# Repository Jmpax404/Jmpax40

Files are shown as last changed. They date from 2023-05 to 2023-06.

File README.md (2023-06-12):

# Jmpax40 v1.0

Jmpax40 is a 40% wireless split keyboard.

## Tips

- 键位设置(/firmware/jmpax/jmpax.keymap)由在线配置工具完成，可以参考[https://github.com/Jmpax404/zmk-config](https://github.com/Jmpax404/zmk-config)

## Troubles

- 钢板卫星轴下面的PCB贴了元器件，导致无法平放卫星轴
- 定位板厚度打的3mm，导致无法卡入卫星轴，应该改用1.5mm的方案
- PCB上的3535正贴灯的标识是按照标准定义设置的，但是力创商城上[XL-3535RGBC-WS2812B](https://item.szlcsc.com/3033137.html)的引脚与其不一致
- 想做Nums、Caps等指示灯，但是ZMK官方仓库目前可能还没有这个功能

## References

感谢大佬们的开源和分享！

学习完下面的参考资料，您也能制作出属于自己的机械键盘。

[C_Go777 - [新手向]自制化键盘教程](https://space.bilibili.com/341864346/channel/collectiondetail?sid=196200)

[苏达酱 - 学完你就该去开团啦！](https://space.bilibili.com/7555349/channel/collectiondetail?sid=153786)

[人菜瘾大周传雄 - 从零制作蓝牙双模键盘DIY](https://space.bilibili.com/95393302/channel/collectiondetail?sid=8167)

[Joric - Jorne Wiki](https://github.com/joric/jorne/wiki)

[Joric - nRFMicro Wiki](https://github.com/joric/nrfmicro/wiki)

[ZMK官方文档](https://zmk.dev/docs)

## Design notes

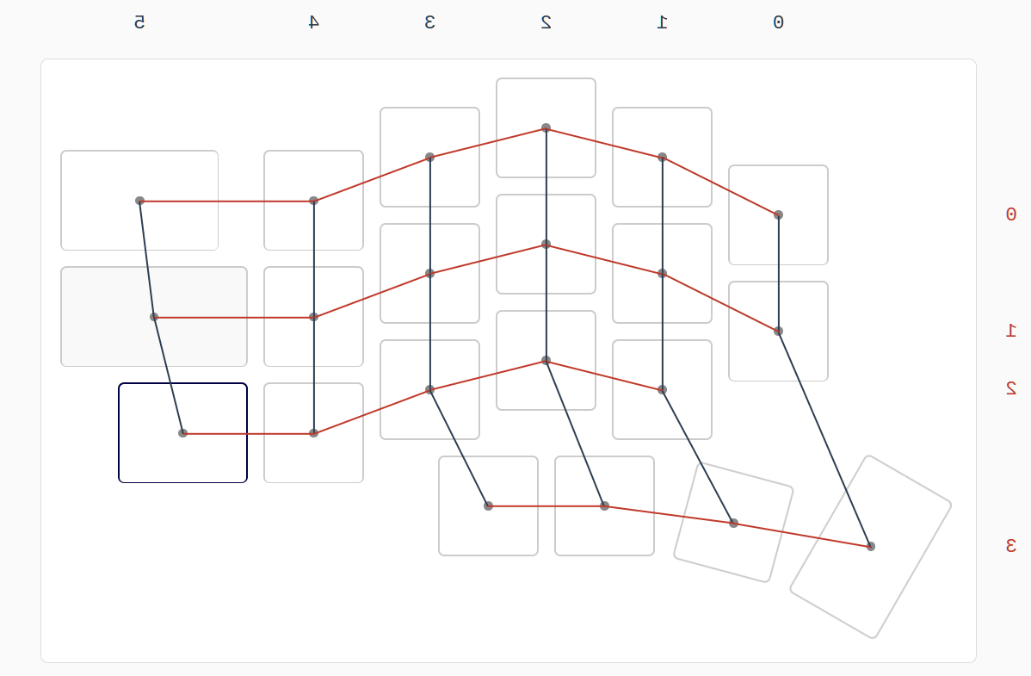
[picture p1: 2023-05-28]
pcb/matrix-right.png

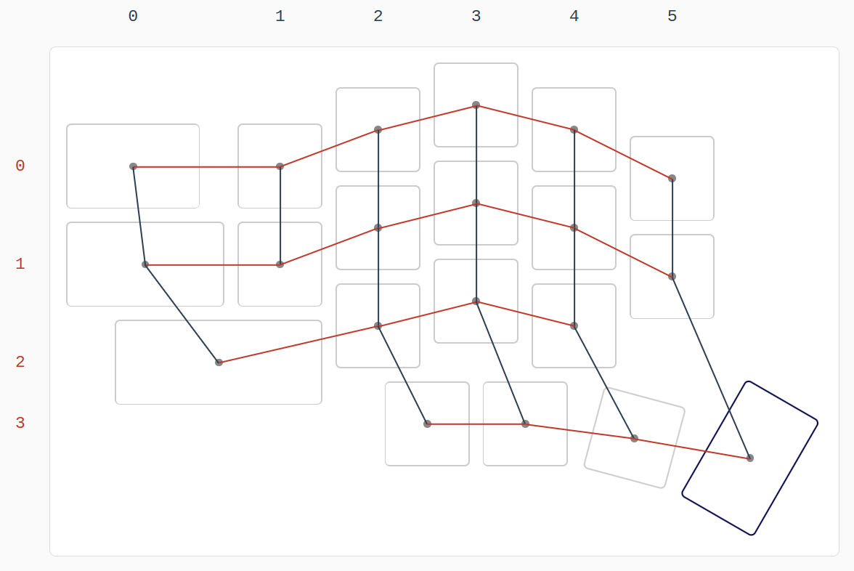
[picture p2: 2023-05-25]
pcb/matrix-left.png

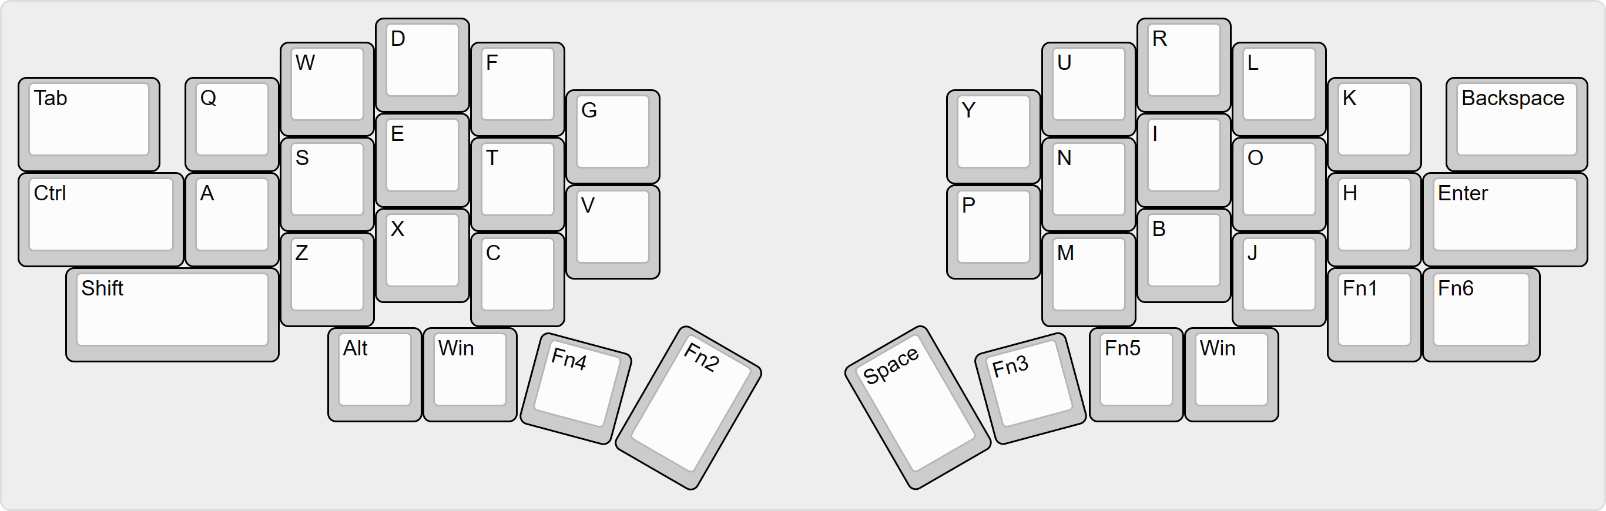
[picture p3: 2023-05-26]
layout/keyboard-layout.png

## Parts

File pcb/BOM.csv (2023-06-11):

ID | Name | Designator | Footprint | Quantity | Store | Price(券前) | 备注
1 | 1N4148W T4 | 一个轴一个 | SOD-123_L2.8-W1.8-LS3.7-RD | 41 | https://item.szlcsc.com/2456.html | 3.29 | 50个
2 | XL-3535RGBC-WS2812B | 一面6个 | SMD3535 | 12 | https://item.szlcsc.com/3033137.html | 13.19 | 15个 | 注意与其他地方卖的灯针脚不同
3 | XL-1010RGBC-WS2812B | 只有右手边 | LED-SMD_4P-L1.0-W1.0-TL_XL-1010RGBC-WS2812B | 3 | https://item.szlcsc.com/6136402.html | 3.91 | 10个
4 | 排母2.54mm 1x40P | 数量为孔的数量 | 塑高3mm | 56 | https://item.szlcsc.com/525918.html | 10.22 | 2个
5 | Kailh热插拔轴座 | 一个轴一个 | PG1511 | 41 | https://item.taobao.com/item.htm?id=692380045185 | 17.35 | 45个
6 | WS2812B 3528 反贴 | 一个轴一个，多配列那里用2回 | 3528/6028 | 44 | https://item.taobao.com/item.htm?id=641768137254 | 12.69 | 50个
7 | Switch3x4x2 | 一边一个 | 2脚 | 2 | https://detail.tmall.com/item.htm?abbucket=0&id=558374381395&ns=1&skuId=4109021943304 | 2.42 | 20个
8 | 内螺纹空心六角螺柱M2*6mm | 一边6个 | 铜柱 | 12 | https://detail.tmall.com/item.htm?abbucket=0&id=41574313055&ns=1&skuId=4807282856605 | 1 | 20个
9 | 304圆头螺栓M2x5 | 包括了保护罩 | M2x5 | 32 | https://detail.tmall.com/item.htm?id=37753866337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 | 1.3 | 100个
10 | 304六角杯头螺栓M5x45 |  |  | 看需求 | https://detail.tmall.com/item.htm?id=529586487467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 | 5.45 | 20个
11 | 304圆头螺丝螺母垫片套装M5*18 |  |  | 看需求 | https://detail.tmall.com/item.htm?id=575980436845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 | 4.9 | 20个
12 | 内螺纹空心六角螺柱M2*12mm | 保护罩的螺柱 | 铜柱 | 4 | https://detail.tmall.com/item.htm?_u=a2u7ds90dae5&id=41574313055&skuId=4985273047422 | 1.5 | 20个
13 | 锂电池聚合物301230 |  |  | 2 | https://detail.tmall.com/item.htm?abbucket=0&id=687976778245&ns=1&skuId=4904401437104 | 13.6 | 2个

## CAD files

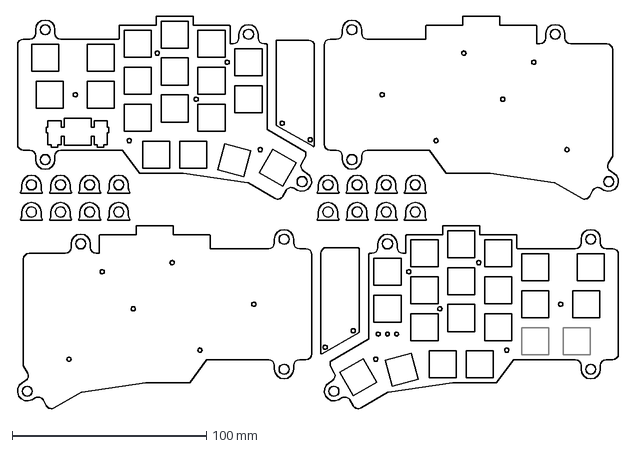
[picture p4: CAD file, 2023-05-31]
plate/plates.dxf
311.1 x 202.4 mm

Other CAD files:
plate/total.dwg

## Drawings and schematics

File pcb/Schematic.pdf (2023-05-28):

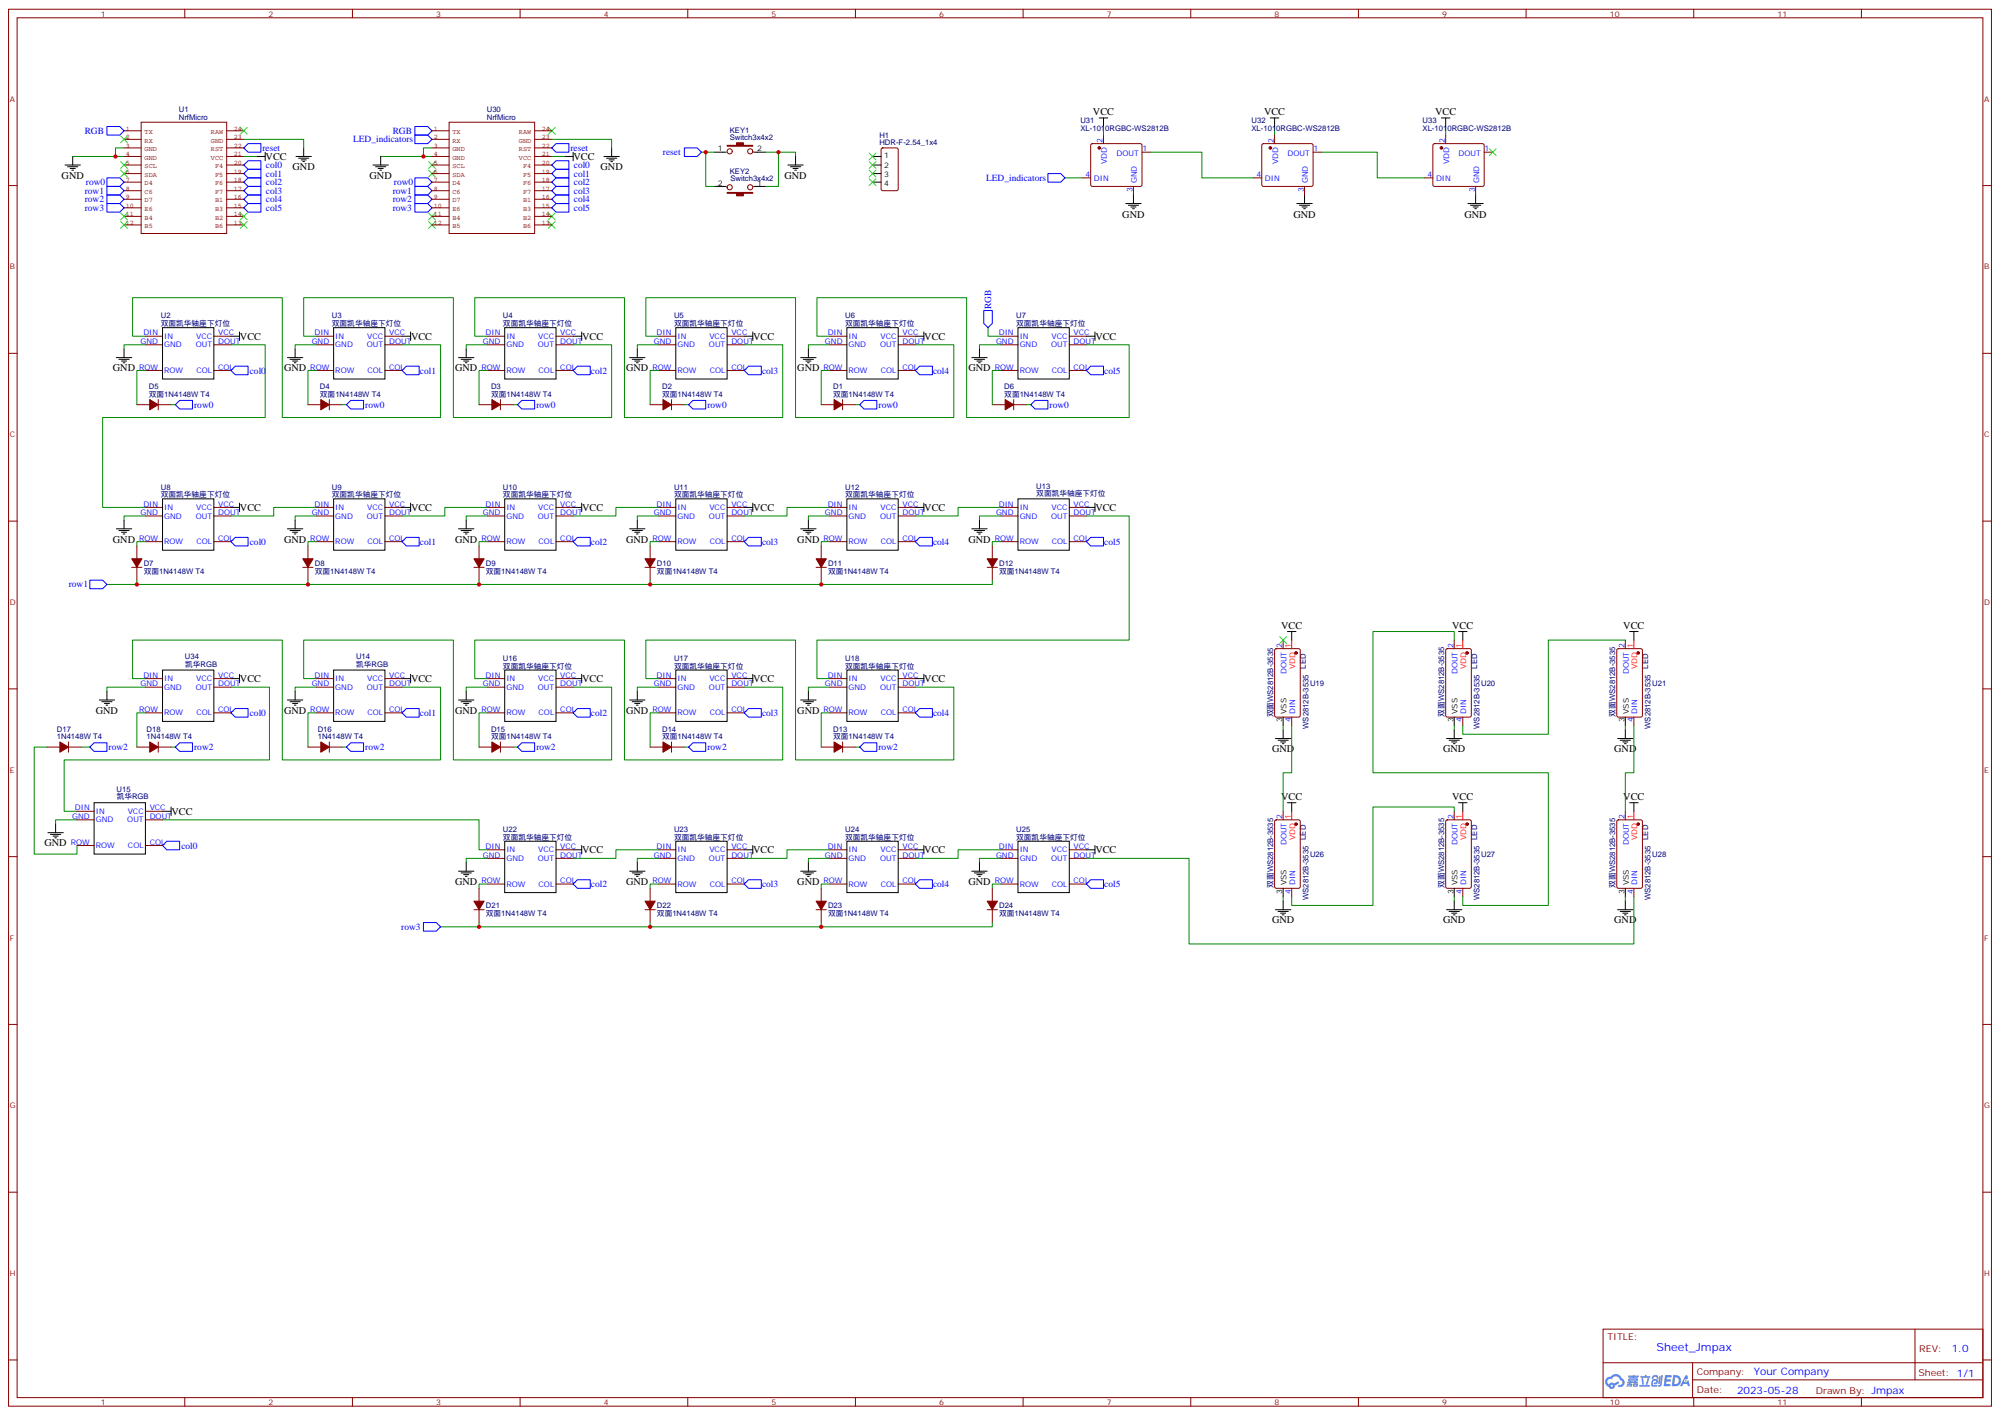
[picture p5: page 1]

OUT DOUT VCC VCC

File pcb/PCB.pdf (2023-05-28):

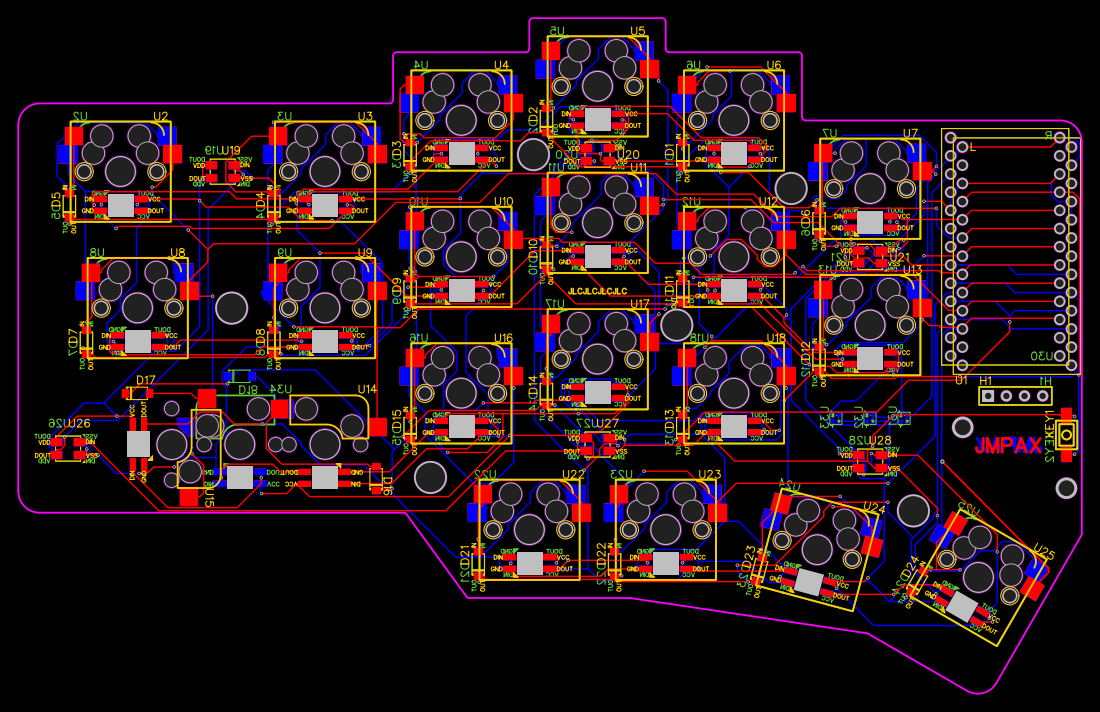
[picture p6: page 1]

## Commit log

2023-05-21 “init”
2023-05-25 布局导出
    [pcb-base.dwg, pcb-base.dxf]
2023-05-25 pcb基板边框完成
    [pcb-base.dwg]
2023-05-25 已完成pcb基板的焊盘开孔和边框圆角
    [pcb-base.dwg, pcb-base.dxf]
2023-05-26 screen protector的开孔完成
    [pcb-base.dwg]
2023-05-26 增加1mm的键盘指示灯，准备元器件摆放
    [pcb-base-real.dxf, pcb-base.dwg]
2023-05-28 PCB制作并下单完成
    [BOM.csv, pcb-base-real.dxf, pcb-base.dwg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]
2023-05-29 元件清单完成
    [BOM.csv]
2023-05-31 已购买完元器件和外壳
    [BOM.csv, pcb-base.dwg, plates.dxf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]
2023-06-08 我的这个场景不应该使用submodule
2023-06-08 更新readme
2023-06-10 修改BOM信息，更新固件
    [BOM.csv]
2023-06-11 单手操作加入空格
2023-06-11 删掉BOM的螺母保护帽，因为没啥用
    [BOM.csv]
